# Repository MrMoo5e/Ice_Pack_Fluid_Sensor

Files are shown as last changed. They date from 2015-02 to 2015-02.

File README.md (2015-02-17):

# Ice_Pack_Fluid_Sensor
Sensor to detect leaks after a plastic cap has been welded on and relay the information to a PLC. 
The program reads a RobotCore water sensor with an arduino analog pin and outputs a 24V signal to the PLC input pin.
The sensor is supposed to sense droplets of the ice pack fluid that drip out of the cap when a bottle with a bad weld is 
squeezed.

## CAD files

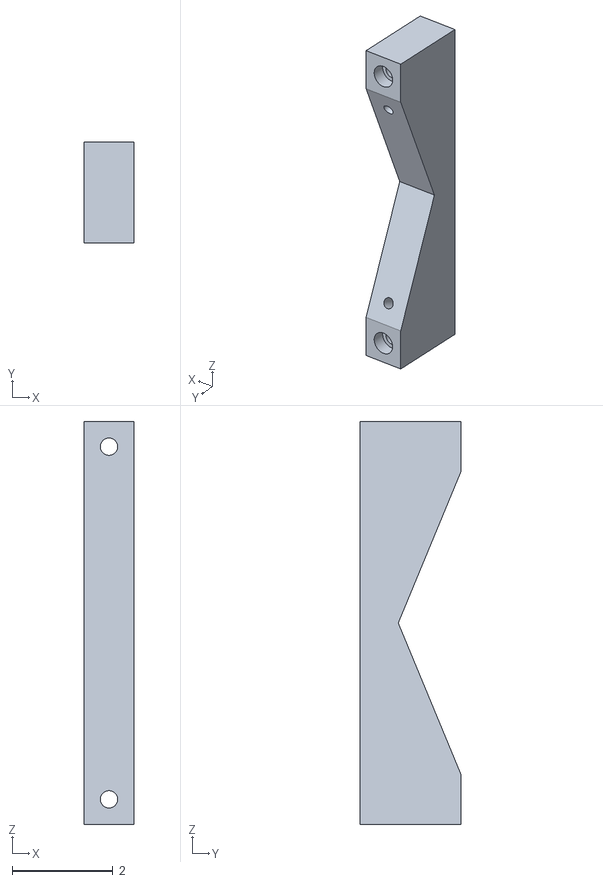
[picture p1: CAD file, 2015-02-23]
Hydrophobic_Ramp - Ramp_Mount-2.STL
1.00 x 2.00 x 8.00

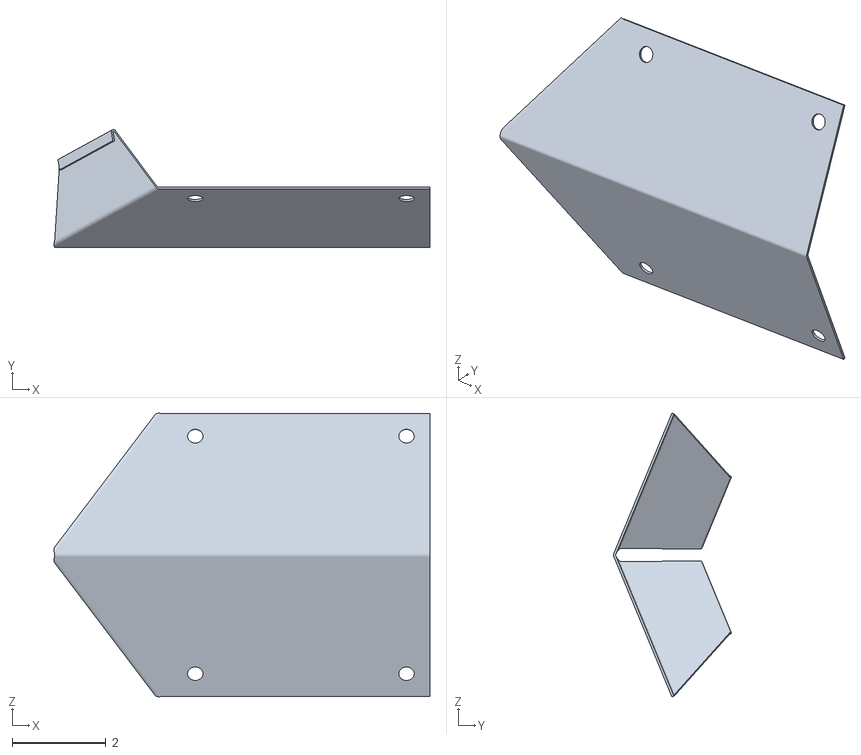
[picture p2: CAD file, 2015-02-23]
Hydrophobic_Ramp - Sheet_Metal_Channel-1.STL
8.01 x 2.51 x 6.04

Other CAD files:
Hydrophobic_Ramp - Ramp_Mount-1.STL

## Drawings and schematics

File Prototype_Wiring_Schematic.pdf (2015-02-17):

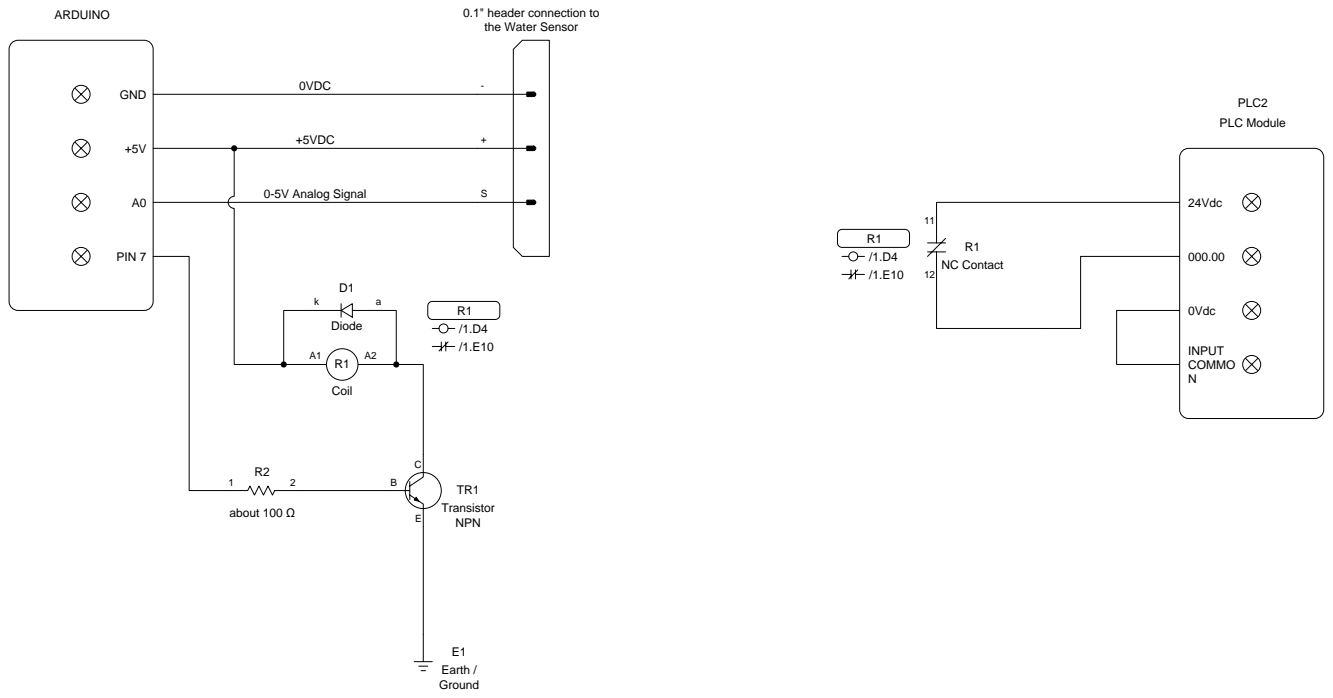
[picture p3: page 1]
Transistor NPN; a Diode; GND; ARDUINO; PIN 7; A2 Coil; +5VDC 0-5V Analog Signal; 2 about 100 Ω; Earth / Ground; 24Vdc; 0Vdc; PLC Module; INPUT COMMO N; PLC2; 12 NC Contact R1

0.1" header connection to the Water Sensor 0VDC

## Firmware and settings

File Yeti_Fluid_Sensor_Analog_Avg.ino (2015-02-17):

// declares global variables below
int sensorPin = A0;    // select the input pin for the potentiometer
int ledPin = 13;      // select the pin for the LED
int sensOutput = 7;
int sensorValue = 0;  // variable to store the value coming from the sensor
int sensorValue2 = 0;
int sensorValue3 = 0;
int sensorValue4 = 0;
void setup() {
  // set pins as inputs and outputs:
  pinMode(ledPin, OUTPUT);
  pinMode(sensOutput, OUTPUT);
  Serial.begin(9600); 
}



void loop() {
  sensorValue = analogRead(sensorPin);   // read the inital value from the sensor
  delay(5);
  sensorValue2 = analogRead(sensorPin);  // reads a second value from the sensor after the above delay
  delay(5);
  sensorValue3 = analogRead(sensorPin);  //reads a 3rd value from the sensor after the above delay
  float SensorAvg = 0;
  float SensorSum = 0;
  int SensorInst = 0;
  SensorSum = sensorValue + sensorValue2 + sensorValue3; // takes the sum of the 3 sensor readings
  SensorAvg = SensorSum/3;  // divides by 3 to get the average
  Serial.println(sensorValue, DEC); // Writes the sensorValue in DEC to the terminal 
  delay(10);
  Serial.println(SensorAvg, DEC);  // writes the average value to the teminal in decimal
  delay(10);
  //Reads the sensor value to compare to the average
  sensorValue4 = analogRead(sensorPin);
  //subtracts the threshold of change from the sensor value
  SensorInst = sensorValue4 - 5;
  if(SensorInst > SensorAvg) {
    digitalWrite(sensOutput, LOW);
    digitalWrite(ledPin, HIGH);
    delay(1000);
  }
  // sets a threshold that ignores the averaging incase the board gets flooded 
  if (SensorInst > 700){
    digitalWrite(sensOutput, LOW);  //controls the pin to the relay. Because the relay is NC this actually puts 24v to the output
    digitalWrite(ledPin, HIGH);  // turns on the on board LED
    delay(50); 
  }
  else {
    digitalWrite(sensOutput, HIGH);  // Stops voltage from flowing throught the relay
    digitalWrite(ledPin, LOW);  // turns the led off
    delay(10); 
  }    
  
}

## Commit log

2015-02-17 Prototype Sensor Video
    Video of the prototype sensor working with compensation. It can sense
    small drops of water without being wiped off in between by averaging 3
    readings over a short time and comparing it to a 4th reading.
2015-02-17 Wiring Schematic and Arduino Sketch
    Wiring schematic and program for the prototype sensor in the video.
2015-02-23 Sheet metal Ramp
    Ramp to channel the ice pack fluid to one point so the sensing area can
    be smaller. Made from galvanized sheet metal coated in Rustoleum Never
    Wet superhydrophobic spray paint so the fluid runs down the ramp easily
    [Hydrophobic_Ramp - Ramp_Mount-1.STL, Hydrophobic_Ramp - Ramp_Mount-2.STL, Hydrophobic_Ramp - Sheet_Metal_Channel-1.STL]
